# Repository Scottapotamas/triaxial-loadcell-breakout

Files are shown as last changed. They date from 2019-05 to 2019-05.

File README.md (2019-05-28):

# Triaxial Load Cell Interface Breakout

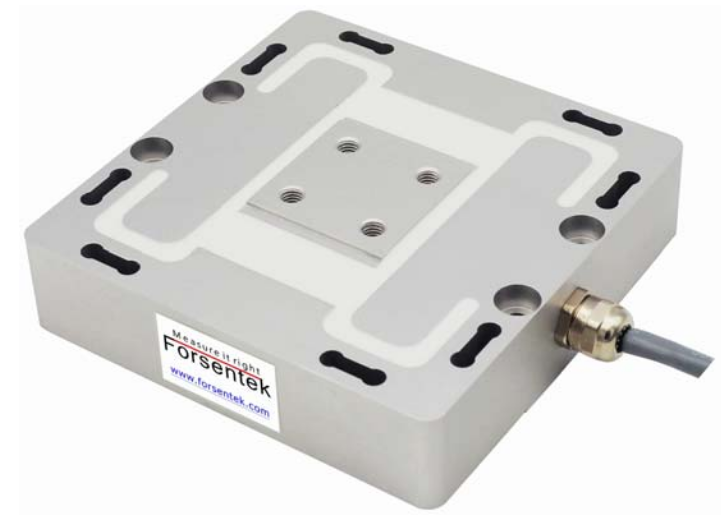
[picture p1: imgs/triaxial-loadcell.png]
triaxial-loadcell


Sourcing the NAU7802 seems easier than the HX711, and I2C suits my application nicely. The NAU7802 featured on [Sparkfun's Qwiic Scale breakout board](https://learn.sparkfun.com/tutorials/qwiic-scale-hookup-guide) has a hardcoded single I2C address, meaning only *one* loadcell can be put on a single I2C bus. 

I wanted to connect a triaxial load cell (3-dof, translational +- in xyz), so this breakout board puts 3x NAU7802 behind an I2C mux, a Texas Instruments TCA9548 8-channel mux (only channels 0, 1, 2 are used).

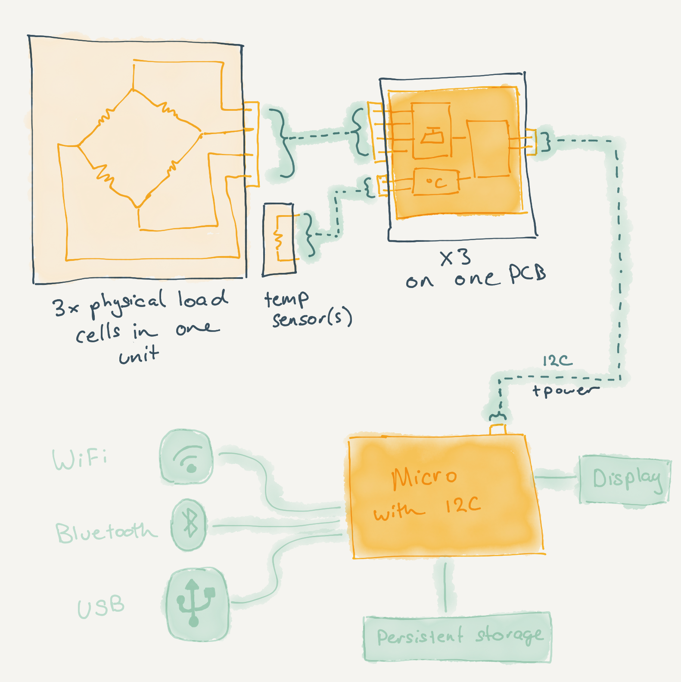
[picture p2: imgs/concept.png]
concept-diagram


Access to the second analog channel of the NAU7802 is provided with the intent of connecting 10k NTC thermistors. This could be used for monitoring the load cell temperature (or multiple load cells if they aren't a single unit). For my application these monitor the temperatures of other elements undergoing temperature cycling.

## Hardware

A Qwiic header is included as a 'backwards compatibility layer' to the existing breakout design. If no software changes are made to Sparkfun's examples, the first channel of this board should behave identically to the single-channel Sparkfun breakout.

The 2.54mm header provides I2C, mux reset, and the ADC data-ready pins.

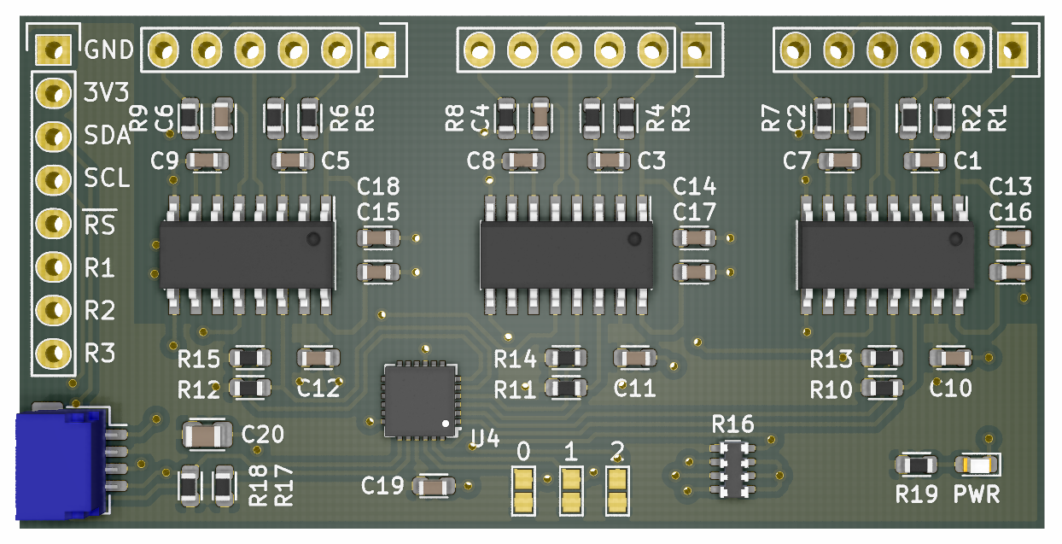
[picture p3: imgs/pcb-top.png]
pcb-top-render
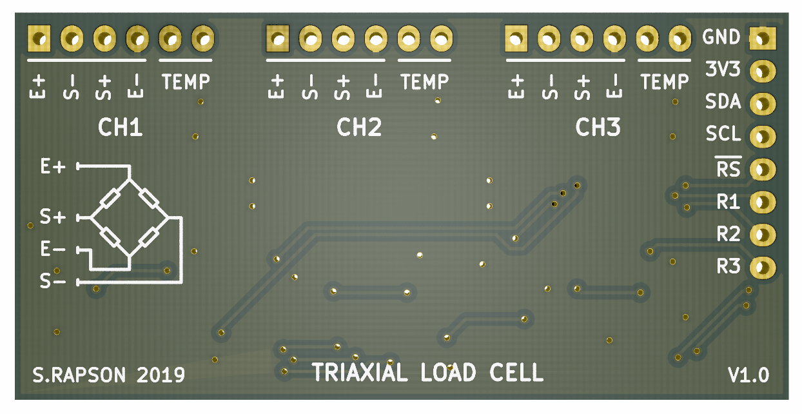
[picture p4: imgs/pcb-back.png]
pcb-back-render


The solder jumpers labelled `0`, `1` and `2` change the I2C address of the I2C multiplexer. With the jumpers untouched, the address of the mux is `0x70`. These allow addresses between `0x70` to `0x77` to be used.

The general software flow is as follows:

- Telling the TCA9548 mux which output you want to use, (write `1 << channelNum` at `0x70`)
- Configure and read the NAU7802 at it's fixed base address of `0x2A`.
- Change the I2C mux to the next channel, configure and sample, repeat across channels.

Optionally, the data-ready pins of the 3 NAU7802 load cell amplifiers are exposed on the header, and these can indicate when a given load cell has completed aquisition and is ready for read-out.

### Multiple breakouts on one bus

If connecting multiple of these 3-axis boards to the same I2C bus, set the mux to a empty channel when accessing another board, as there can only be the *one* NAU7802 on the bus. By selecting an empty channel on the other breakouts, there won't be any conflicts.

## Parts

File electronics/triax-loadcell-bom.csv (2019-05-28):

Title: | Triaxial Loadcell Breakout
Rev: | V1.0
Source: | /Users/scott/projects/triaxial-loadcell-breakout/electronics/triax-loadwing.sch
Date: | Tuesday, 28 May 2019 at 11:49:19 am
Component Count: | 52
Ref | Qty | Value | Description | Manf | Manf# | Installed | Footprint
C1, C3, C5, C7, C8, C9, C13, C14, C15 | 9 | 100n_X7R_1608M | CAP, MLCC, X7R, 100NF, 50V, 0603 | KEMET | C0603C104K5RACAUTO |  | CAPC1608X90N
C16, C17, C18, C19 | 4 | 1u_X7R_1608M | CAP, MLCC, X7R, 1UF, 50V, 0603 | muRata | GRM188R61H105KAALD |  | CAPC1608X90N
C2, C4, C6, C10, C11, C12 | 6 | 100n_1608M | CAP, MLCC, X7R, 100NF, 50V, 0603 | KEMET | C0603C104K5RACAUTO |  | CAPC1608X90N
C20 | 1 | 10u_X7R_2012M | CAP, MLCC, X7R, 10UF, 6.3V, 0805, 2012M | MULTICOMP | MC0805B106K6R3CT |  | CAPC2012X110N
D1 | 1 | LED_RED_1608M | DIALIGHT ChipLED Red, 0603, 1608M | DIALIGHT | 5988010107F |  | LEDC1608X80L40N
JP1, JP2, JP3 | 3 | JUMPER-LINK-2 |  |  |  | DNP | SJ1608-2N
P1, P2, P3 | 3 | CONN_01X06 | Pin Header, 2.54mm, Vertical, PTH, 6 Way, 1 Row, 01x06 | WURTH | 61300611121 | DNP | 61300611121
P4 | 1 | CONN_01X08 | Pin Header, 2.54mm, Vertical, PTH, 8 Way, 1 Row, 01x08 | WURTH | 61300811121 | DNP | 61300811121
P5 | 1 | JST_SH_4_RA | JST SH/SR Series, 1.00mm Pitch, 4 Way, Shrouded Right Angle, PCB Header, Surface Mount | JST | SM04B-SRSS-TB(LF)(SN) |  | SM04B-SRSS-TB
R1, R2, R3, R4, R5, R6 | 6 | 47R_1608M | RESISTOR, THICK FILM, 47R, 100mW, 0603, 1608M | PANASONIC | ERJ3GEYJ470V |  | RESC1608X50N
R16 | 1 | 10K_QUAD_ARRAY_1608M | RESISTOR, THICK FILM, 10K, 5%, 0603, 1608M, QUAD ARRAY | BI TECHNOLOGIES | BCN164A103J7 |  | R_Array_Concave_4x1608M
R19 | 1 | 1K00_1608M | RESISTOR, THICK FILM, 1K, 125mW, 1%, 0603, 1608M | MULTICOMP | MCHP03W8F1001T5E |  | RESC1608X50N
R7, R8, R9, R10, R11, R12, R13, R14, R15, R17, R18 | 11 | 4K7_1608M | RESISTOR, THICK FILM, 100K, 125mW, 1%, 0603, 1608M | MULTICOMP | MC0063W060354K7 |  | RESC1608X50N
U1, U2, U3 | 3 | NAU7802 | A/D Converter, 24-Bit, 2-input, Delta-Sigma, load/bridge whetstone sensors, I2C Interface, 2.7V-5.5V | Nuvoton | NAU7802SGI |  | SOIC16P127_990X600X175L83X41N
U4 | 1 | TCA9548A | I2C 8-channel multiplexer, 8:1 mux, 1.65-5.5V, 24QFN | TEXAS INSTRUMENTS | TCA9548ARGER |  | QFN25P50_400X400X100L40X24T270N
Tool: | Eeschema (5.1.0-0)
Script: | /Users/scott/projects/ecad/scripts/BOM/bom/BOM-GroupedByValue.py

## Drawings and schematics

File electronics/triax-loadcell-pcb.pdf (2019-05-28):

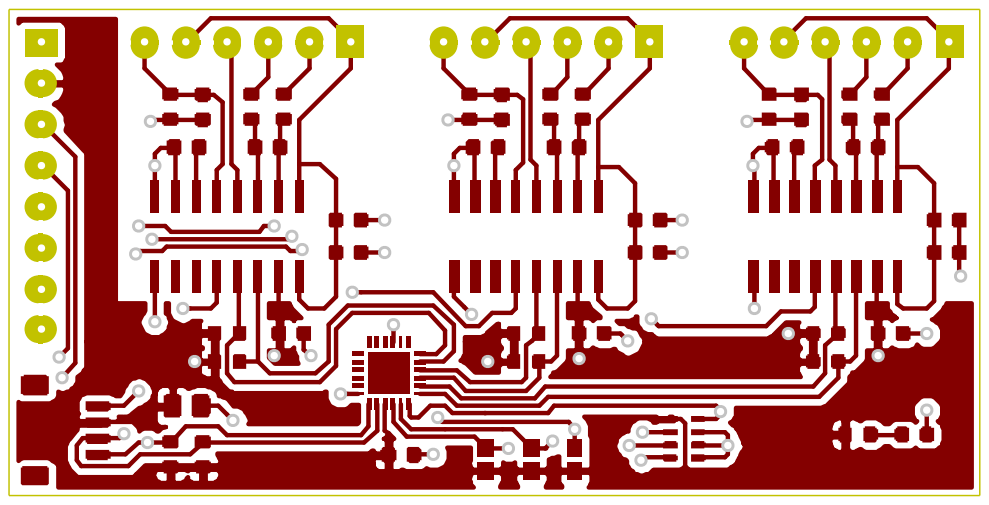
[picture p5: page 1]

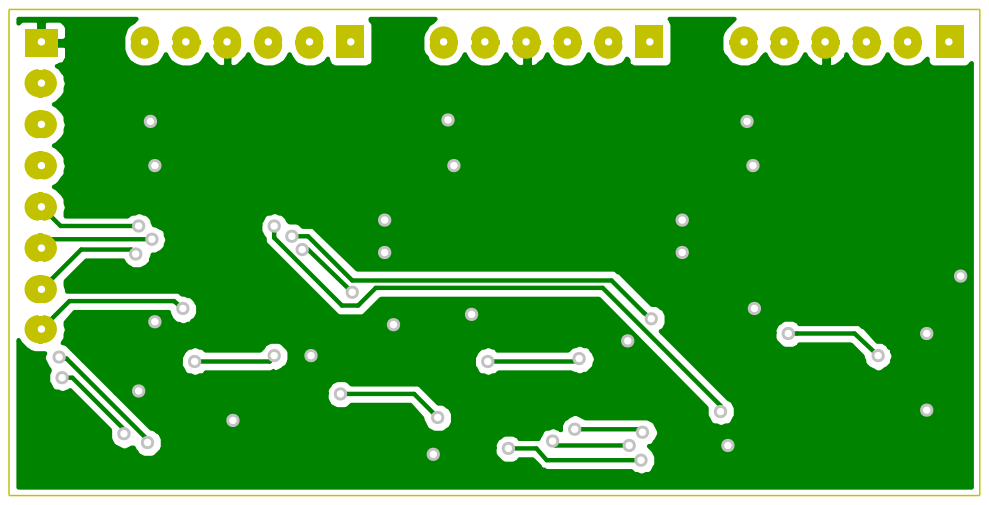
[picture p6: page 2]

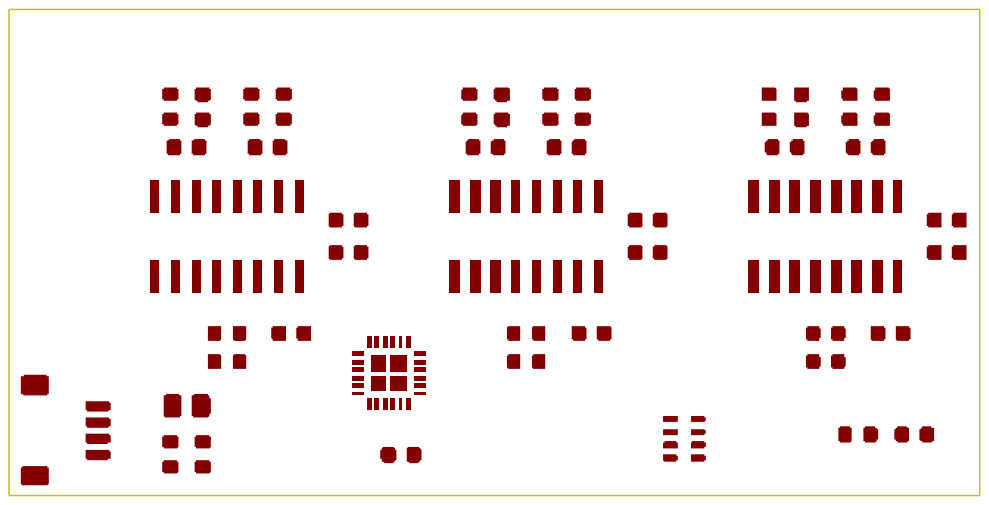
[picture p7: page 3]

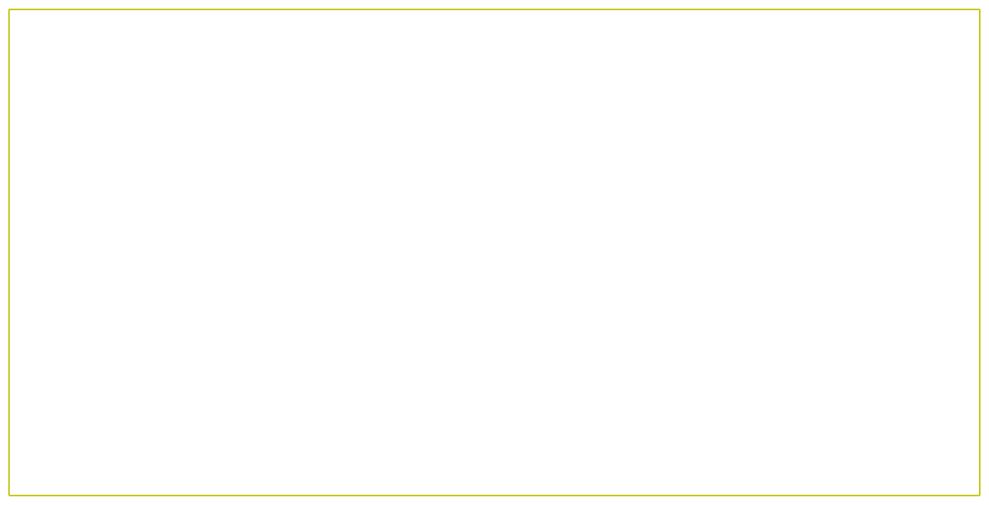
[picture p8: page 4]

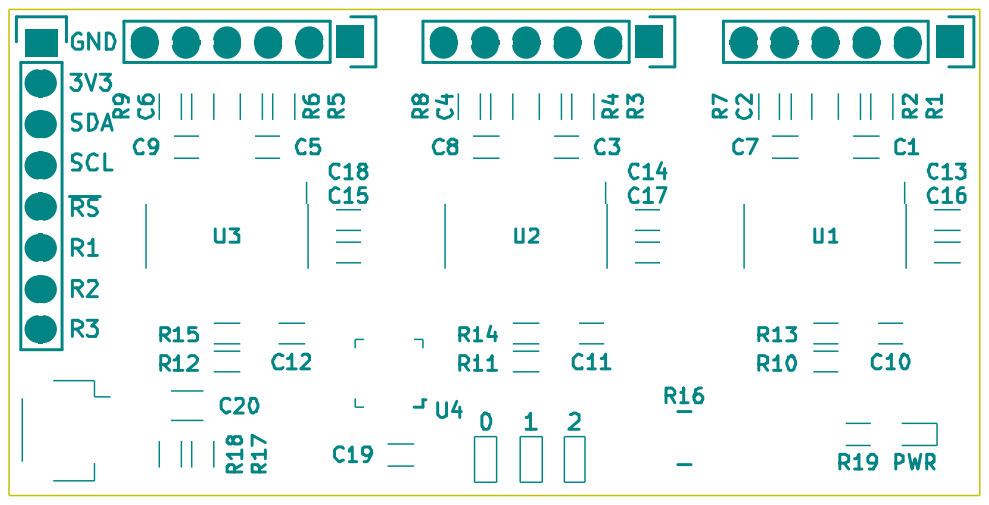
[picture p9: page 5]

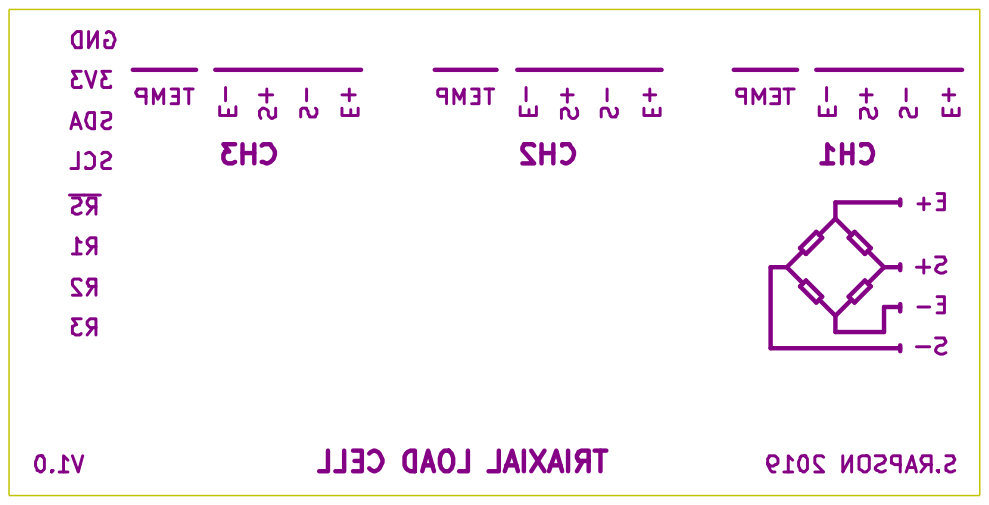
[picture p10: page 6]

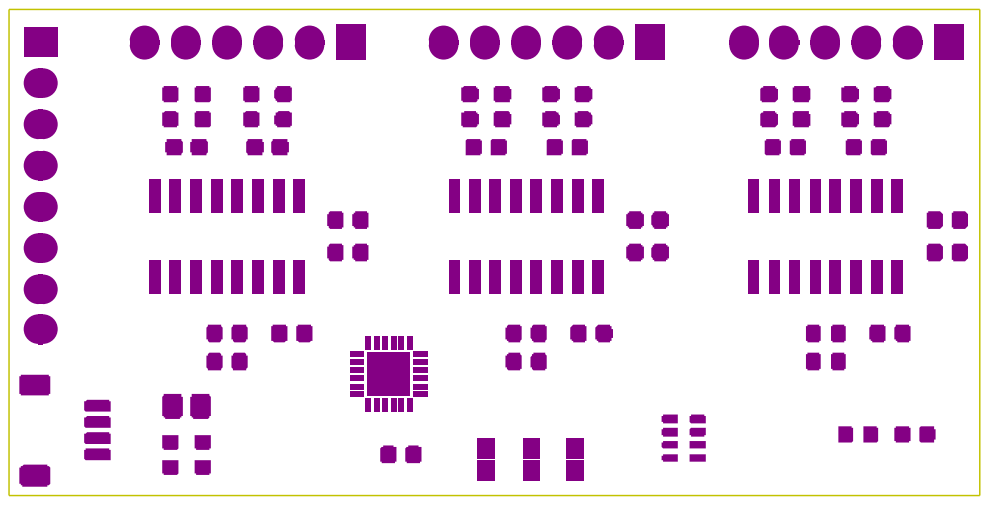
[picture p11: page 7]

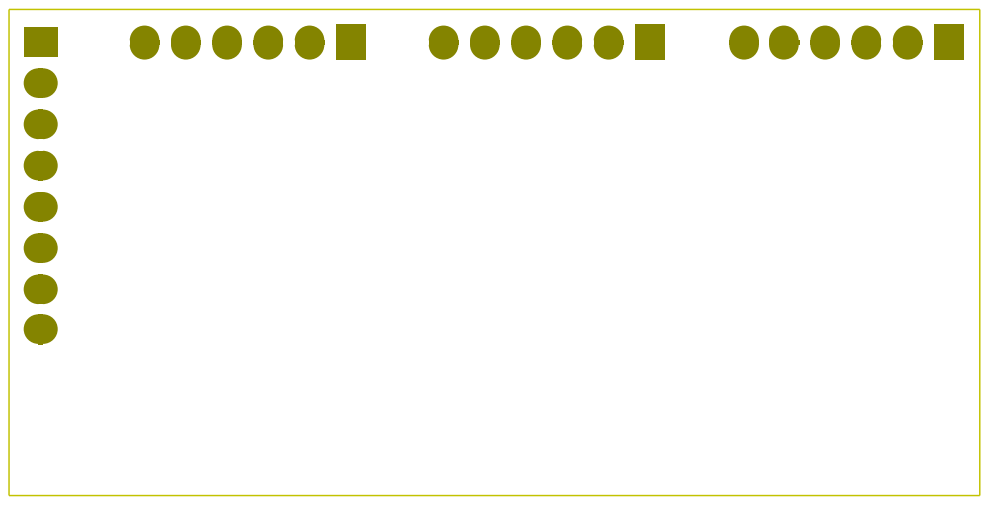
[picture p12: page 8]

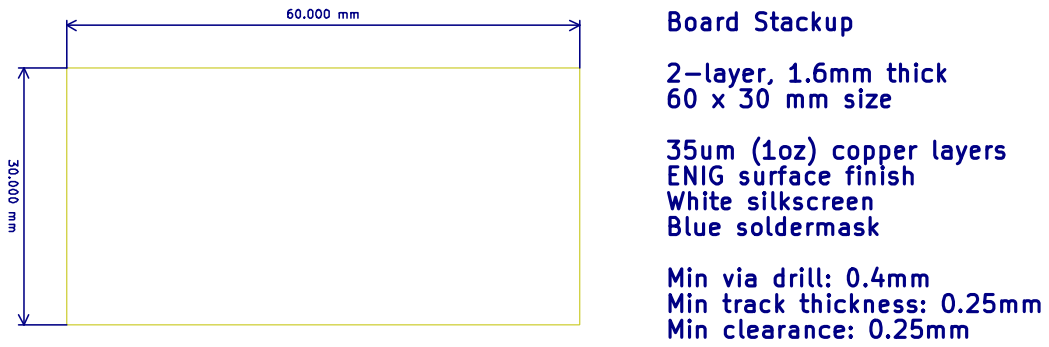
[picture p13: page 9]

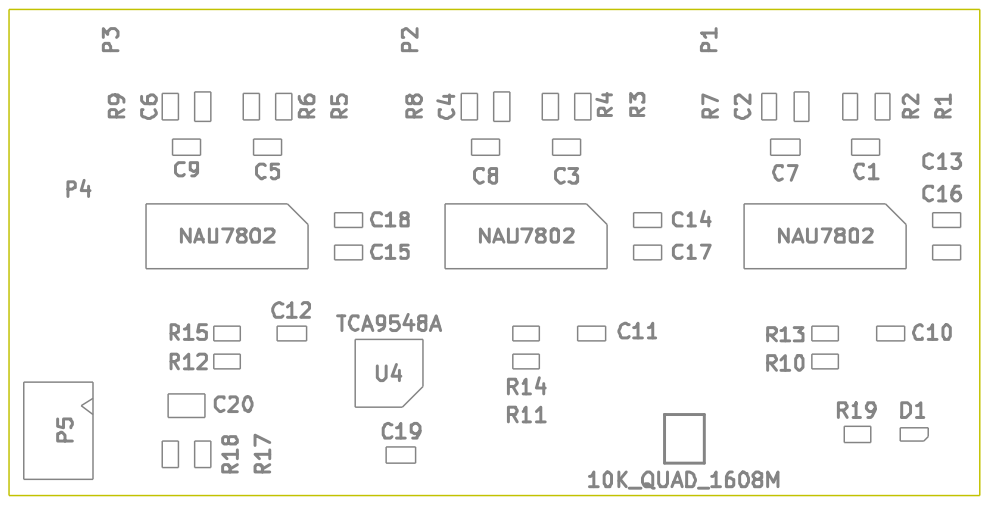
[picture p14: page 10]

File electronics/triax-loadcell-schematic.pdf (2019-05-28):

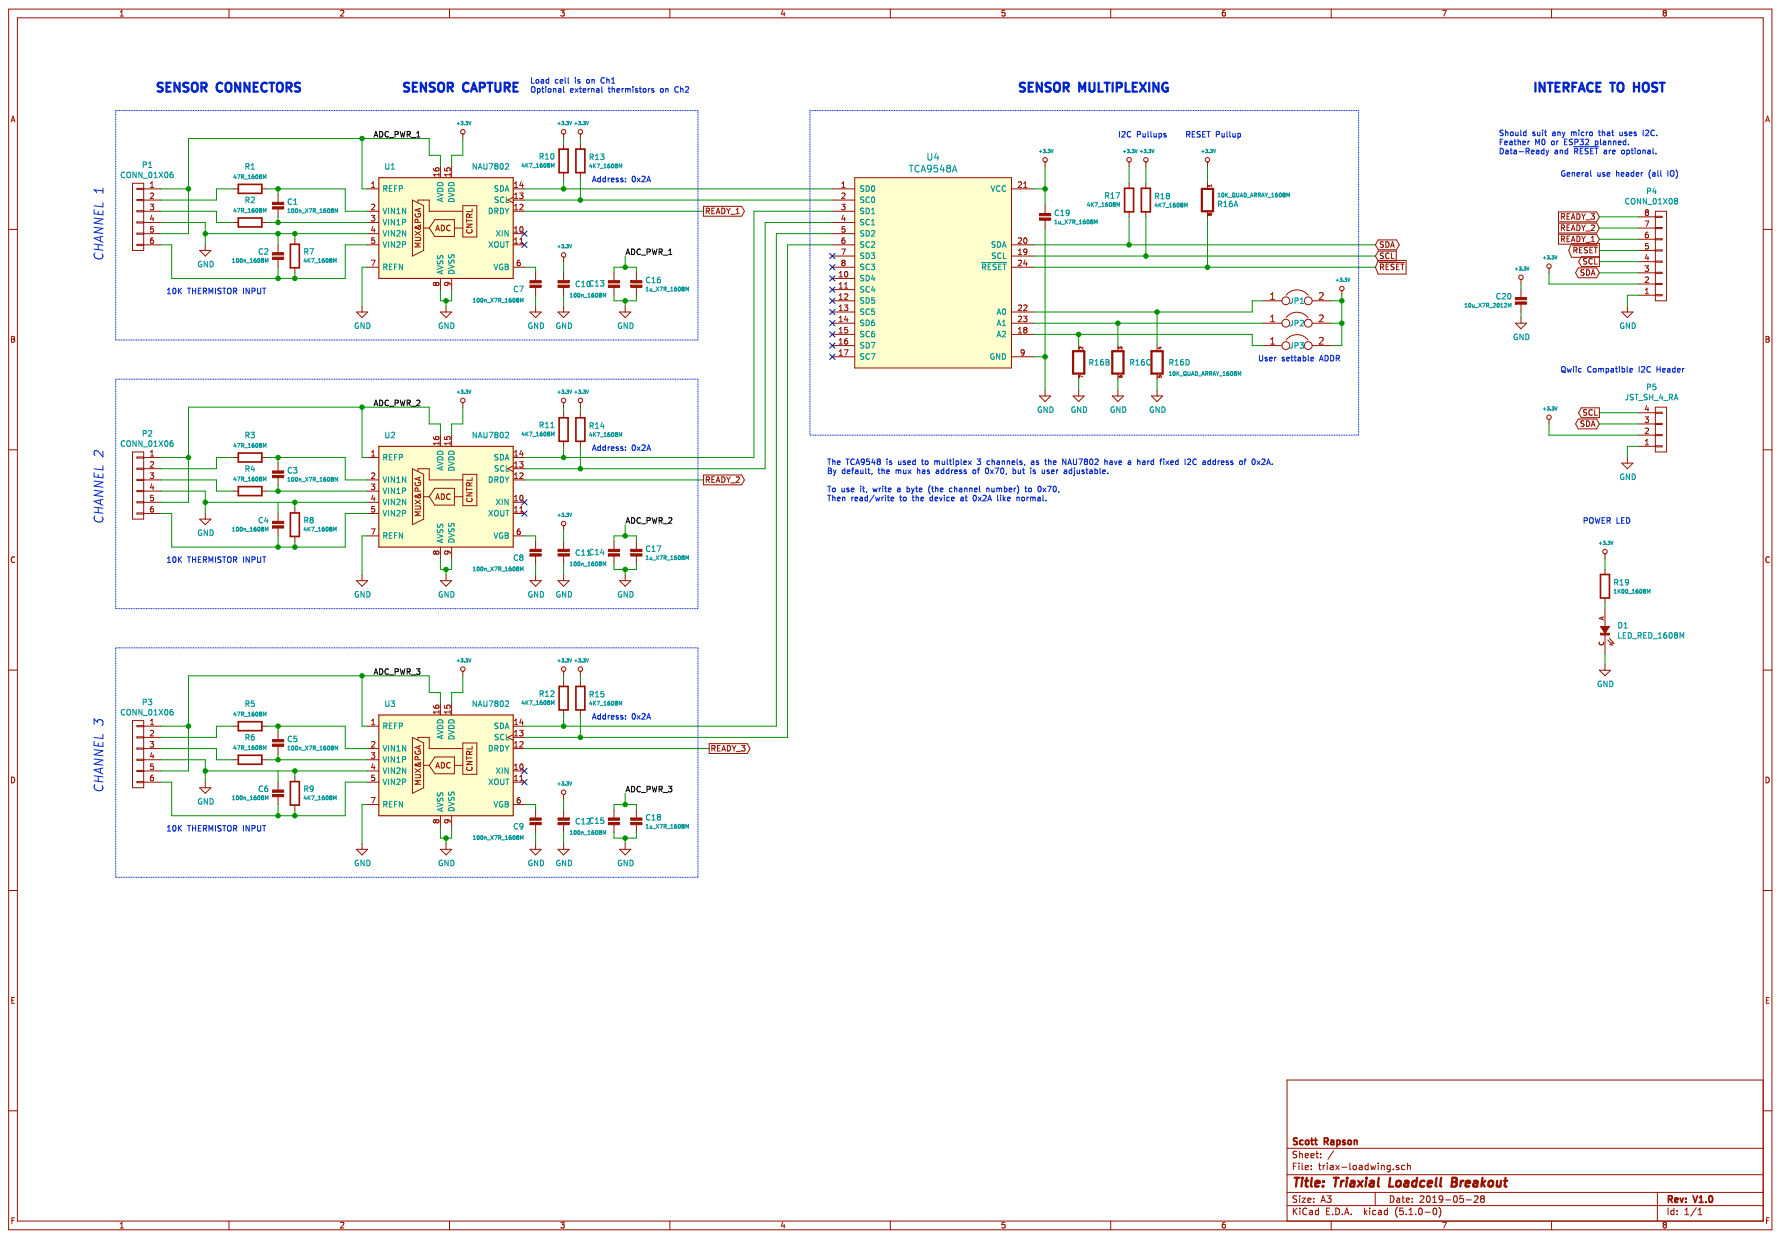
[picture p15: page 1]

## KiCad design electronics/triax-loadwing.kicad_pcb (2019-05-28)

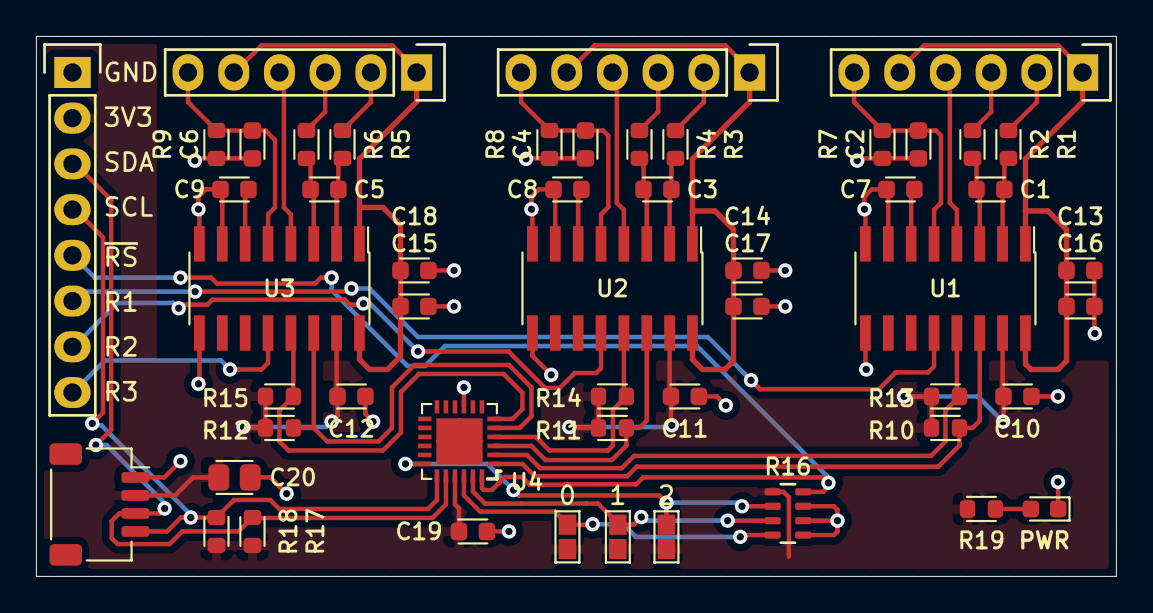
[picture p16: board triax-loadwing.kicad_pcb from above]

Board: 2 copper layers, 60.0 x 30.0 mm, 52 parts (0 on the bottom side), 39 nets.

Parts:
C1, C3, C5, C7, C8, C9, C13, C14, C15: 100n_X7R_1608M; CAPC1608X90N
C2, C4, C6, C10, C11, C12: 100n_1608M; CAPC1608X90N
C16, C17, C18, C19: 1u_X7R_1608M; CAPC1608X90N
C20: 10u_X7R_2012M; CAPC2012X110N
D1: LED_RED_1608M; LEDC1608X80L40N
JP1, JP2, JP3: JUMPER-LINK-2; SJ1608-2N
P1, P2, P3: CONN_01X06; 61300611121
P4: CONN_01X08; 61300811121
P5: JST_SH_4_RA; SM04B-SRSS-TB
R1, R2, R3, R4, R5, R6: 47R_1608M; RESC1608X50N
R7, R8, R9, R10, R11, R12, R13, R14, R15, R17, R18: 4K7_1608M; RESC1608X50N
R16: 10K_QUAD_1608M; R_Array_Concave_4x1608M
R19: 1K00_1608M; RESC1608X50N
U1, U2, U3: NAU7802; SOIC16P127_990X600X175L83X41N
U4: TCA9548A; QFN25P50_400X400X100L40X24T270N

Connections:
+3.3V: C10.1, C11.1, C12.1, C19.1, C20.2, JP1.2, JP2.2, JP3.2, P4.2, P5.2, R10.2, R11.2, R12.2, R13.1, R14.1, R15.1, R16.1, R17.2, R18.1, R19.1, U1.15, U2.15, U3.15, U4.21
/ADC_PWR_1: C13.2, C16.1, P1.1, P1.5, U1.1, U1.16
/ADC_PWR_2: C14.2, C17.1, P2.1, P2.5, U2.1, U2.16
/ADC_PWR_3: C15.2, C18.1, P3.1, P3.5, U3.1, U3.16
GND: C2.2, C4.2, C6.2, C7.1, C8.1, C9.1, C10.2, C11.2, C12.2, C13.1, C14.1, C15.1, C16.2, C17.2, C18.2, C19.2, C20.1, D1.C, P1.4, P2.4, P3.4, P4.1, P5.1, R7.2, R8.2, R9.2, R16.5, R16.6, R16.7, U1.4, U1.7, U1.8, U1.9, U2.4, U2.7, U2.8, U2.9, U3.4, U3.7, U3.8, U3.9, U4.9
unnamed: C1.1, R1.1, U1.2
unnamed: C1.2, R2.1, U1.3
unnamed: C2.1, P1.6, R7.1, U1.5
unnamed: C3.1, R3.1, U2.2
unnamed: C3.2, R4.1, U2.3
unnamed: C4.1, P2.6, R8.1, U2.5
unnamed: C5.1, R5.1, U3.2
unnamed: C5.2, R6.1, U3.3
unnamed: C6.1, P3.6, R9.1, U3.5
unnamed: C7.2, U1.6
unnamed: C8.2, U2.6
unnamed: C9.2, U3.6
unnamed: D1.A, R19.2
unnamed: JP1.1, R16.4, U4.22
unnamed: JP2.1, R16.3, U4.23
unnamed: JP3.1, R16.2, U4.18
unnamed: P1.2, R1.2
unnamed: P1.3, R2.2
unnamed: P2.2, R3.2
unnamed: P2.3, R4.2
unnamed: P3.2, R5.2
unnamed: P3.3, R6.2
unnamed: R10.1, U1.14, U4.1
unnamed: R11.1, U2.14, U4.3
unnamed: R12.1, U3.14, U4.5
unnamed: R13.2, U1.13, U4.2
unnamed: R14.2, U2.13, U4.4
unnamed: R15.2, U3.13, U4.6
READY_1: P4.6, U1.12
READY_2: P4.7, U2.12
READY_3: P4.8, U3.12
SCL: P4.4, P5.4, R18.2, U4.19
SDA: P4.3, P5.3, R17.1, U4.20
~RESET: P4.5, R16.8, U4.24

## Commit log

2019-05-14 Started schematic
    [triax-loadwing.sch]
2019-05-16 Fleshing out schematic
    [triax-loadwing.sch]
2019-05-20 Fleshing out schematic - removed feather compatibility
    [triax-loadwing.sch]
2019-05-21 PCB started
    [triax-loadwing.kicad_pcb]
2019-05-21 Adds board renders
2019-05-21 Routing complete
    [triax-loadwing.kicad_pcb, triax-loadwing.sch]
2019-05-28 Cosmetics final pass
    [triax-loadwing.kicad_pcb]
2019-05-28 Titleblocks, pcb manf notes
    [triax-loadwing.kicad_pcb, triax-loadwing.sch]
2019-05-28 Added concept block diagram and pcb renders to README
    Also improves docs
2019-05-28 PDF exports
    [triax-loadwing.kicad_pcb]
2019-05-28 Gerber export
    [triax-loadwing-B_Cu.gbl, triax-loadwing-B_Fab.gbr, triax-loadwing-B_Mask.gbs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]
2019-05-28 BOM for fab
    CSV and HTML with parts links
    [triax-loadcell-bom.csv]
